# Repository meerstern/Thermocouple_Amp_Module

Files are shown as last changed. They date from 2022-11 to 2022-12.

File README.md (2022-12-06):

# 熱電対センサアンプ基板
Thermocouple_Amp_Module with MAX31855K & STM32G030F6P6

## 概要
  * [MAX31855K][1]を使用したK型熱電対センサ用のアンプ基板です  
  * K型熱電対の温度に応じてアナログ出力(0~3.3V)を得ることが可能です  
  * JP1のOpenでローゲインモード(既定)、Closeでハイゲインモードの切替が可能です  
  * ローゲインモードの場合、ゲイン200℃/V、オフセット1.25Vで、温度範囲は-240℃～400℃です  
  * ハイゲインモードの場合、ゲイン400℃/V、オフセット1.25Vで、温度範囲は-270℃～800℃です  

  * 計算式  $K型熱電対温度 ℃ ＝ ゲイン × (電圧出力-オフセット)$  

 * 電源投入直後及び熱電対の断線や短絡等の異常時は基板上のエラーLED(赤色)が点灯します  
 * STM32G030F6P6マイコンのコードを公開しているため、ゲインやオフセットを変更することが可能です  
 * アナログ出力はマイコンのPWM出力(16bit)からローパスフィルタとバッファを介して出力しています  
 * 電源電圧が5Vであってもアナログ出力範囲は0~3.3Vです  
 * 変換精度±4℃、最大±6℃  
 * アナログ出力範囲の上限及び下限ではオフセット電圧や飽和電圧の影響で温度精度が低下する場合があります  
 * 電源電圧が3.3Vより低い場合、アナログ出力が低下する場合があります  
 * ファーム書き換えはSTLink及びSTM32CubeProgrammerが別途必要です  
 * 電源電圧：3.3V~5V  
 * 基板サイズ25mm x35mm、M3x2 幅19mm  
 
 ## 販売サイト
  * [スイッチサイエンス][2]
 
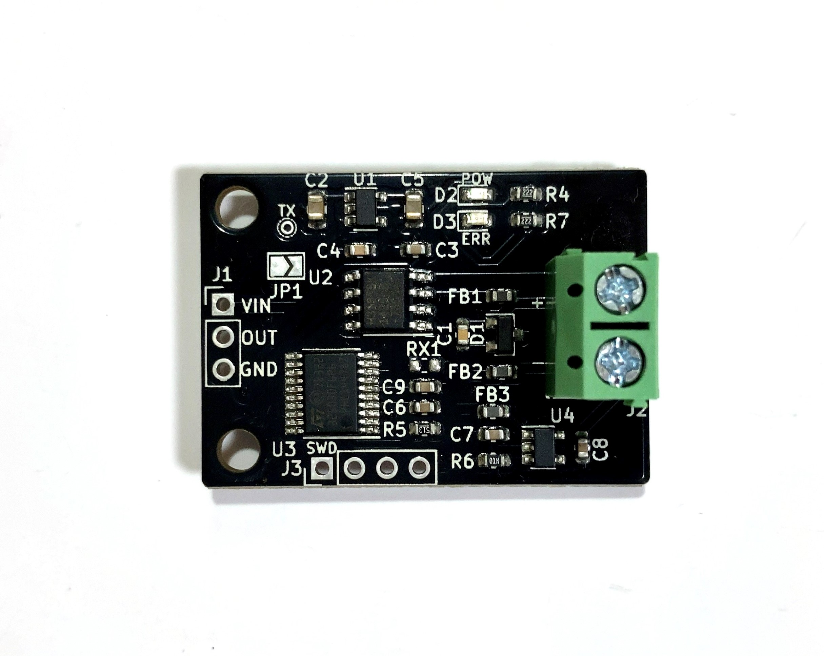
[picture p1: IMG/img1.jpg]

   
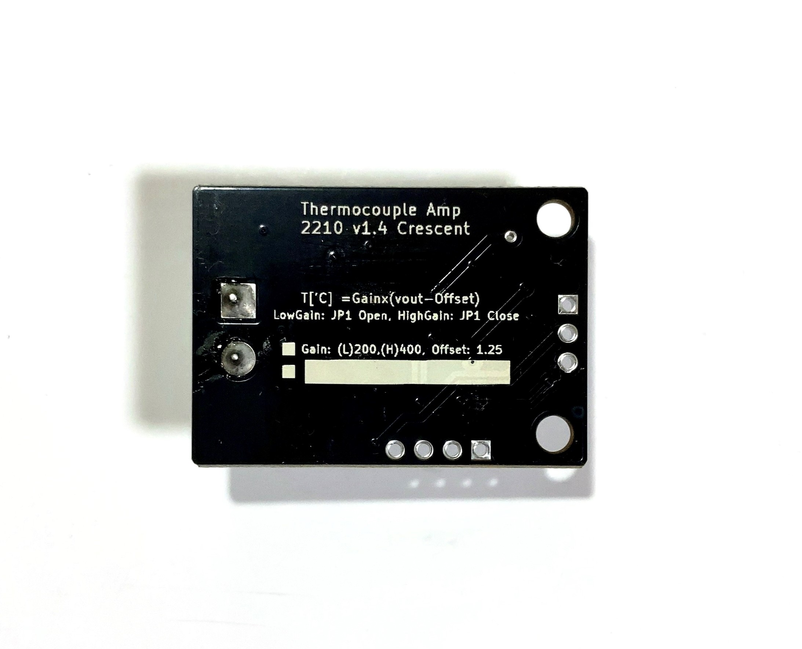
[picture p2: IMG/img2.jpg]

 
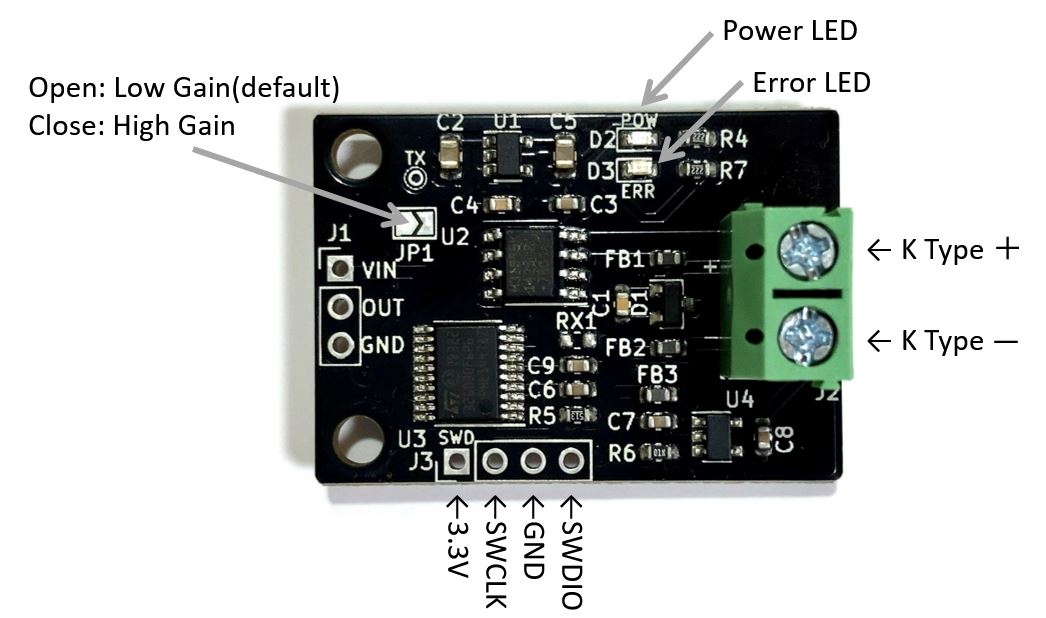
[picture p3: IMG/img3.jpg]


[1]: https://www.maximintegrated.com/jp/products/interface/sensor-interface/MAX31855.html
[2]: https://www.switch-science.com/products/8651

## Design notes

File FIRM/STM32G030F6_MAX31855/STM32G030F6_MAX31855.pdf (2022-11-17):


22/09/2022

STM32G030F6_MAX31855 Project Configuration Report

## 1. Description

### 1.1. Project

Project Name | STM32G030F6_MAX31855
Board Name | custom
Generated with: | STM32CubeMX 6.2.1
Date | 09/22/2022

### 1.2. MCU

MCU Series | STM32G0
MCU Line | STM32G0x0 Value line
MCU name | STM32G030F6Px
MCU Package | TSSOP20
MCU Pin number | 29

### 1.3. Core(s) information

Core(s) | ARM Cortex-M0+

## 2. Pinout Configuration

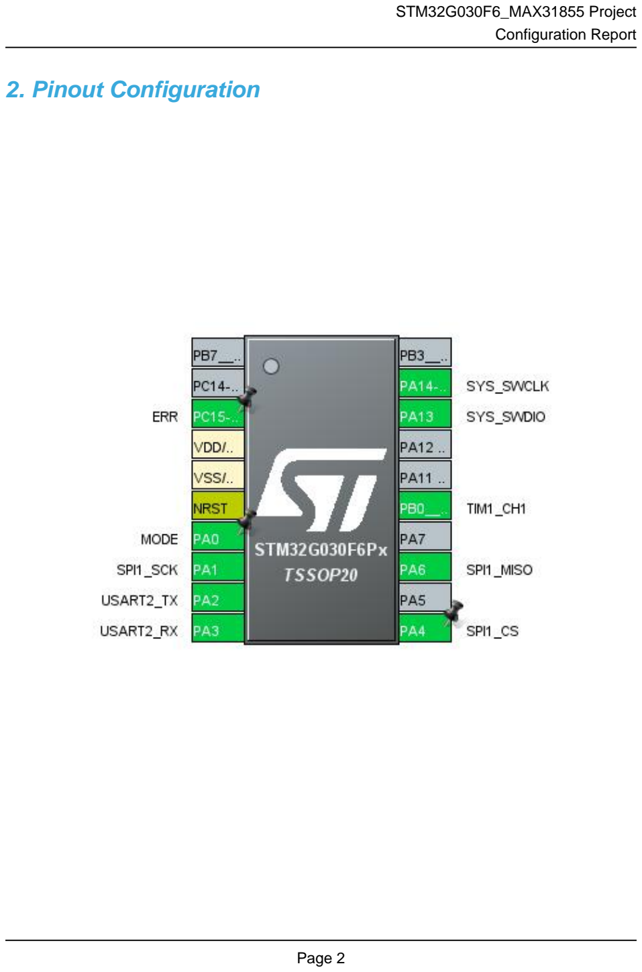
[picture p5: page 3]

## 3. Pins Configuration

Pin Number TSSOP20 | Pin Name (function after reset) | Pin Type | Alternate Function(s) | Label
3 | PC15-OSC32_OUT (PC15) * | I/O | GPIO_Output | ERR
4 | VDD/VDDA | Power
5 | VSS/VSSA | Power
6 | NRST | Reset
7 | PA0 * | I/O | GPIO_Input | MODE
8 | PA1 | I/O | SPI1_SCK
9 | PA2 | I/O | USART2_TX
10 | PA3 | I/O | USART2_RX
11 | PA4 * | I/O | GPIO_Output | SPI1_CS
13 | PA6 | I/O | SPI1_MISO
15 | PA8 | I/O | TIM1_CH1
18 | PA13 | I/O | SYS_SWDIO
19 | PA14-BOOT0 | I/O | SYS_SWCLK

* The pin is affected with an I/O function

## 4. Clock Tree Configuration

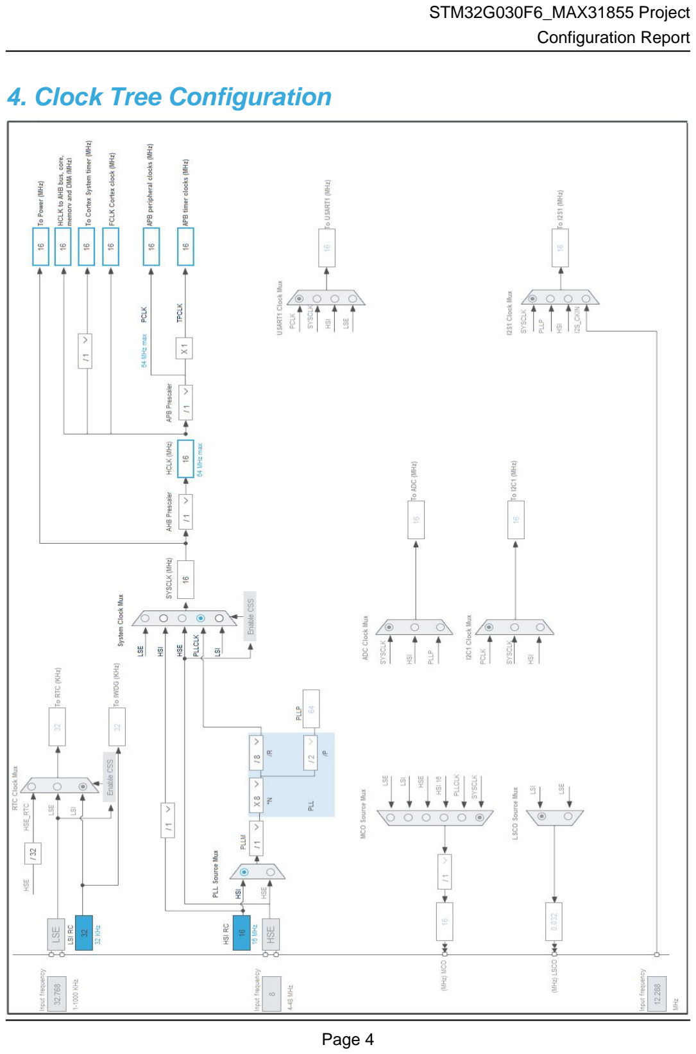
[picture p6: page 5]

## 5. Software Project

### 5.1. Project Settings

Name | Value
Project Name | STM32G030F6_MAX31855
Project Folder | D:\30_ARM_WS\workspace\STM32G030F6_MAX31855
Toolchain / IDE | SW4STM32
Firmware Package Name and Version | STM32Cube FW_G0 V1.4.1
Application Structure | Advanced
Generate Under Root | Yes
Do not generate the main() | No
Minimum Heap Size | 0x200
Minimum Stack Size | 0x400

### 5.2. Code Generation Settings

Name | Value
STM32Cube MCU packages and embedded software | Copy only the necessary library files
Generate peripheral initialization as a pair of '.c/.h' files | No
Backup previously generated files when re-generating | No
Keep User Code when re-generating | Yes
Delete previously generated files when not re-generated | Yes
Set all free pins as analog (to optimize the power consumption) | No
Enable Full Assert | No

### 5.3. Advanced Settings - Generated Function Calls

Rank | Function Name | Peripheral Instance Name
1 | MX_GPIO_Init | GPIO
2 | SystemClock_Config | RCC
3 | MX_SPI1_Init | SPI1
4 | MX_TIM1_Init | TIM1
5 | MX_USART2_UART_Init | USART2

## 6. Power Consumption Calculator report

### 6.1. Microcontroller Selection

Series | STM32G0
Line | STM32G0x0 Value line
MCU | STM32G030F6Px
Datasheet | DS12991_Rev1

### 6.2. Parameter Selection

Temperature | 25
Vdd | 3.0

### 6.3. Battery Selection

Battery | Li-SOCL2(AAA700)
Capacity | 700.0 mAh
Self Discharge | 0.08 %/month
Nominal Voltage | 3.6 V
Max Cont Current | 10.0 mA
Max Pulse Current | 30.0 mA
Cells in series | 1
Cells in parallel | 1

### 6.4. Sequence

Step | Step1 | Step2
Mode | RUN | STOP1
Vdd | 3.0 | 3.0
Voltage Source | Battery | Battery
Range | Range1-High | NoRange
Fetch Type | FLASH | Flash-PowerDown
CPU Frequency | 64 MHz | 16 MHz
Clock Configuration | HSI PLL | HSI
Clock Source Frequency | 16 MHz | 16 MHz
Peripherals
Additional Cons. | 0 mA | 0 mA
Average Current | 5.77 mA | 3.7 µA
Duration | 0.1 ms | 0.9 ms
DMIPS | 80.0 | 0.0
Ta Max | 128.68 | 130
Category | In DS Table | In DS Table

### 6.5. Results

Sequence Time | 1 ms | Average Current | 580.33 µA
Battery Life | 1 month, 19 days, 18 hours | Average DMIPS | 80.0 DMIPS

### 6.6. Chart

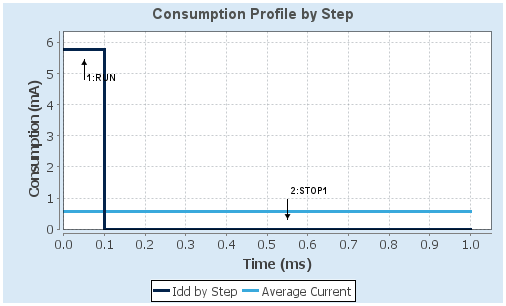
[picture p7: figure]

## 7. Peripherals and Middlewares Configuration

### 7.1. RCC

7.1.1. Parameter Settings:

System Parameters:

VDD voltage (V) | 3.3
Instruction Cache | Enabled
Prefetch Buffer | Disabled
Data Cache | Enabled
Flash Latency(WS) | 0 WS (1 CPU cycle)
RCC Parameters:
HSI Calibration Value | 64
HSE Startup Timout Value (ms) | 100
LSE Startup Timout Value (ms) | 5000
Power Parameters:
Power Regulator Voltage Scale | Power Regulator Voltage Scale 1
Peripherals Clock Configuration:
Generate the peripherals clock configuration | TRUE

### 7.2. SPI1

Mode: Receive Only Master
7.2.1. Parameter Settings:

Basic Parameters:

Frame Format | Motorola
Data Size | 8 Bits
First Bit | MSB First
Clock Parameters:
Prescaler (for Baud Rate) | 16 *
Baud Rate | 1000.0 KBits/s *
Clock Polarity (CPOL) | Low
Clock Phase (CPHA) | 1 Edge
Advanced Parameters:
CRC Calculation | Disabled
NSSP Mode | Enabled
NSS Signal Type | Software

### 7.3. SYS

mode: Debug
Timebase Source: SysTick

### 7.4. TIM1

Channel1: Output Compare CH1
7.4.1. Parameter Settings:

Counter Settings:

Prescaler (PSC - 16 bits value) | 0
Counter Mode | Up
Counter Period (AutoReload Register - 16 bits value ) | 65535
Internal Clock Division (CKD) | No Division
Repetition Counter (RCR - 16 bits value) | 0
auto-reload preload | Disable
Trigger Output (TRGO) Parameters:
Master/Slave Mode (MSM bit) | Disable (Trigger input effect not delayed)
Trigger Event Selection TRGO | Reset (UG bit from TIMx_EGR)
Trigger Event Selection TRGO2 | Reset (UG bit from TIMx_EGR)
Break And Dead Time management - BRK Configuration:
BRK State | Disable
BRK Polarity | High
BRK Filter (4 bits value) | 0
BRK Sources Configuration
- Digital Input | Disable
Break And Dead Time management - BRK2 Configuration:
BRK2 State | Disable
BRK2 Polarity | High
BRK2 Filter (4 bits value) | 0
BRK2 Sources Configuration
- Digital Input | Disable
Break And Dead Time management - Output Configuration:
Automatic Output State | Disable
Off State Selection for Run Mode (OSSR) | Disable
Off State Selection for Idle Mode (OSSI) | Disable
Lock Configuration | Off
Clear Input:
Clear Input Source | Disable

Output Compare Channel 1:

Mode | Frozen (used for Timing base)
Pulse (16 bits value) | 0
Output compare preload | Disable
CH Polarity | High
CH Idle State | Reset

### 7.5. USART2

Mode: Asynchronous
7.5.1. Parameter Settings:

Basic Parameters:

Baud Rate | 9600 *
Word Length | 8 Bits (including Parity)
Parity | None
Stop Bits | 1
Advanced Parameters:
Data Direction | Receive and Transmit
Over Sampling | 16 Samples
Single Sample | Disable
ClockPrescaler | 1
Advanced Features:
TX Pin Active Level Inversion | Disable
RX Pin Active Level Inversion | Disable
Data Inversion | Disable
TX and RX Pins Swapping | Disable
Overrun | Enable
DMA on RX Error | Enable
MSB First | Disable

* User modified value

## 8. System Configuration

### 8.1. GPIO configuration

IP | Pin | Signal | GPIO mode | GPIO pull/up pull down | Max Speed | User Label
SPI1 | PA1 | SPI1_SCK | Alternate Function Push Pull | No pull-up and no pull-down | Low
| PA6 | SPI1_MISO | Alternate Function Push Pull | No pull-up and no pull-down | Low
SYS | PA13 | SYS_SWDIO | n/a | n/a | n/a
| PA14-BOOT0 | SYS_SWCLK | n/a | n/a | n/a
TIM1 | PA8 | TIM1_CH1 | Alternate Function Push Pull | No pull-up and no pull-down | Low
USART2 | PA2 | USART2_TX | Alternate Function Push Pull | No pull-up and no pull-down | Low
| PA3 | USART2_RX | Alternate Function Push Pull | No pull-up and no pull-down | Low
GPIO | PC15-OSC32_OU T (PC15) | GPIO_Output | Output Push Pull | No pull-up and no pull-down | Low | ERR
| PA0 | GPIO_Input | Input mode | Pull-up * | n/a | MODE
| PA4 | GPIO_Output | Output Push Pull | No pull-up and no pull-down | Low | SPI1_CS

### 8.2. DMA configuration

nothing configured in DMA service

### 8.3. NVIC configuration

8.3.1. NVIC
Interrupt Table | Enable | Preenmption Priority | SubPriority
Non maskable interrupt | true | 0 | 0
Hard fault interrupt | true | 0 | 0
System service call via SWI instruction | true | 0 | 0
Pendable request for system service | true | 0 | 0
System tick timer | true | 0 | 0
Flash global interrupt | unused
RCC global interrupt | unused
TIM1 break, update, trigger and commutation interrupts | unused
TIM1 capture compare interrupt | unused
SPI1 global interrupt | unused
USART2 global interrupt / USART2 wake-up interrupt through EXTI line 26 | unused
8.3.2. NVIC Code generation
Enabled interrupt Table | Select for init sequence ordering | Generate IRQ handler | Call HAL handler
Non maskable interrupt | false | true | false
Hard fault interrupt | false | true | false
System service call via SWI instruction | false | true | false
Pendable request for system service | false | true | false
System tick timer | false | true | true

* User modified value

## 9. System Views

9.1. Category view
9.1.1. Current

## 10. Docs & Resources

Type | Link
Datasheet | http://www.st.com/resource/en/datasheet/DM00613878.pdf
Reference manual | http://www.st.com/resource/en/reference_manual/DM00463896.pdf
Programming manual | http://www.st.com/resource/en/programming_manual/DM00104451.pdf
Errata sheet | http://www.st.com/resource/en/errata_sheet/DM00625292.pdf
Application note | http://www.st.com/resource/en/application_note/CD00160362.pdf
Application note | http://www.st.com/resource/en/application_note/CD00167594.pdf
Application note | http://www.st.com/resource/en/application_note/CD00259245.pdf
Application note | http://www.st.com/resource/en/application_note/CD00264342.pdf
Application note | http://www.st.com/resource/en/application_note/CD00264379.pdf
Application note | http://www.st.com/resource/en/application_note/DM00042534.pdf
Application note | http://www.st.com/resource/en/application_note/DM00072315.pdf
Application note | http://www.st.com/resource/en/application_note/DM00081379.pdf
Application note | http://www.st.com/resource/en/application_note/DM00129215.pdf
Application note | http://www.st.com/resource/en/application_note/DM00151811.pdf
Application note | http://www.st.com/resource/en/application_note/DM00257177.pdf
Application note | http://www.st.com/resource/en/application_note/DM00272912.pdf
Application note | http://www.st.com/resource/en/application_note/DM00226326.pdf
Application note | http://www.st.com/resource/en/application_note/DM00355687.pdf
Application note | http://www.st.com/resource/en/application_note/DM00311483.pdf
Application note | http://www.st.com/resource/en/application_note/DM00380469.pdf
Application note | http://www.st.com/resource/en/application_note/DM00395696.pdf
Application note | http://www.st.com/resource/en/application_note/DM00493651.pdf
Application note | http://www.st.com/resource/en/application_note/DM00535045.pdf
Application note | http://www.st.com/resource/en/application_note/DM00443870.pdf
Application note | http://www.st.com/resource/en/application_note/DM00449912.pdf

Application note | http://www.st.com/resource/en/application_note/DM00483659.pdf
Application note | http://www.st.com/resource/en/application_note/DM00536349.pdf
Application note | http://www.st.com/resource/en/application_note/DM00625700.pdf
Application note | http://www.st.com/resource/en/application_note/DM00725181.pdf

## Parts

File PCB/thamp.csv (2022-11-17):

ID | 参照記号 | パッケージ | 数 | 名称 | Supplier and ref
1 | REF1,REF2 | MountingHole_3.2mm_M3 | 2 | MountingHole_3.2mm_M3
2 | FB3,FB2,FB1 | L_0603_1608Metric | 3 | 470ohm
3 | JP1 | SolderJumper-2_P1.3mm_Open_TrianglePad1.0x1.5mm | 1 | SW_DIP_x01
4 | U3 | TSSOP-20_4.4x6.5mm_P0.65mm | 1 | STM32G030F
5 | RX1 | R_0603_1608Metric | 1 | 0
6 | C9,C8,C7,C6,C3 | C_0603_1608Metric | 5 | 0.1u
7 | U4 | SOT-23-5 | 1 | LM321
8 | U2 | SOIC-8_3.9x4.9mm_P1.27mm | 1 | MAX31855KASA
9 | U1 | SOT-23-5 | 1 | LD3985M33R_SOT23
10 | R7,R4 | R_0603_1608Metric | 2 | 2.1k
11 | R6 | R_0603_1608Metric | 1 | 10
12 | R5 | R_0603_1608Metric | 1 | 51k
13 | J3 | PinHeader_1x04_P2.54mm_Vertical | 1 | SWD
14 | J2 | TerminalBlock_bornier-2_P5.08mm | 1 | Thermocouple
15 | J1 | PinHeader_1x03_P2.54mm_Vertical | 1 | Conn_01x03
16 | D3 | LED_0603_1608Metric | 1 | ERR
17 | D2 | LED_0603_1608Metric | 1 | POW
18 | D1 | SOT-23 | 1 | NUP2105L
19 | C5,C2 | C_0805_2012Metric | 2 | 10u
20 | C4,C1 | C_0603_1608Metric | 2 | 0.01u

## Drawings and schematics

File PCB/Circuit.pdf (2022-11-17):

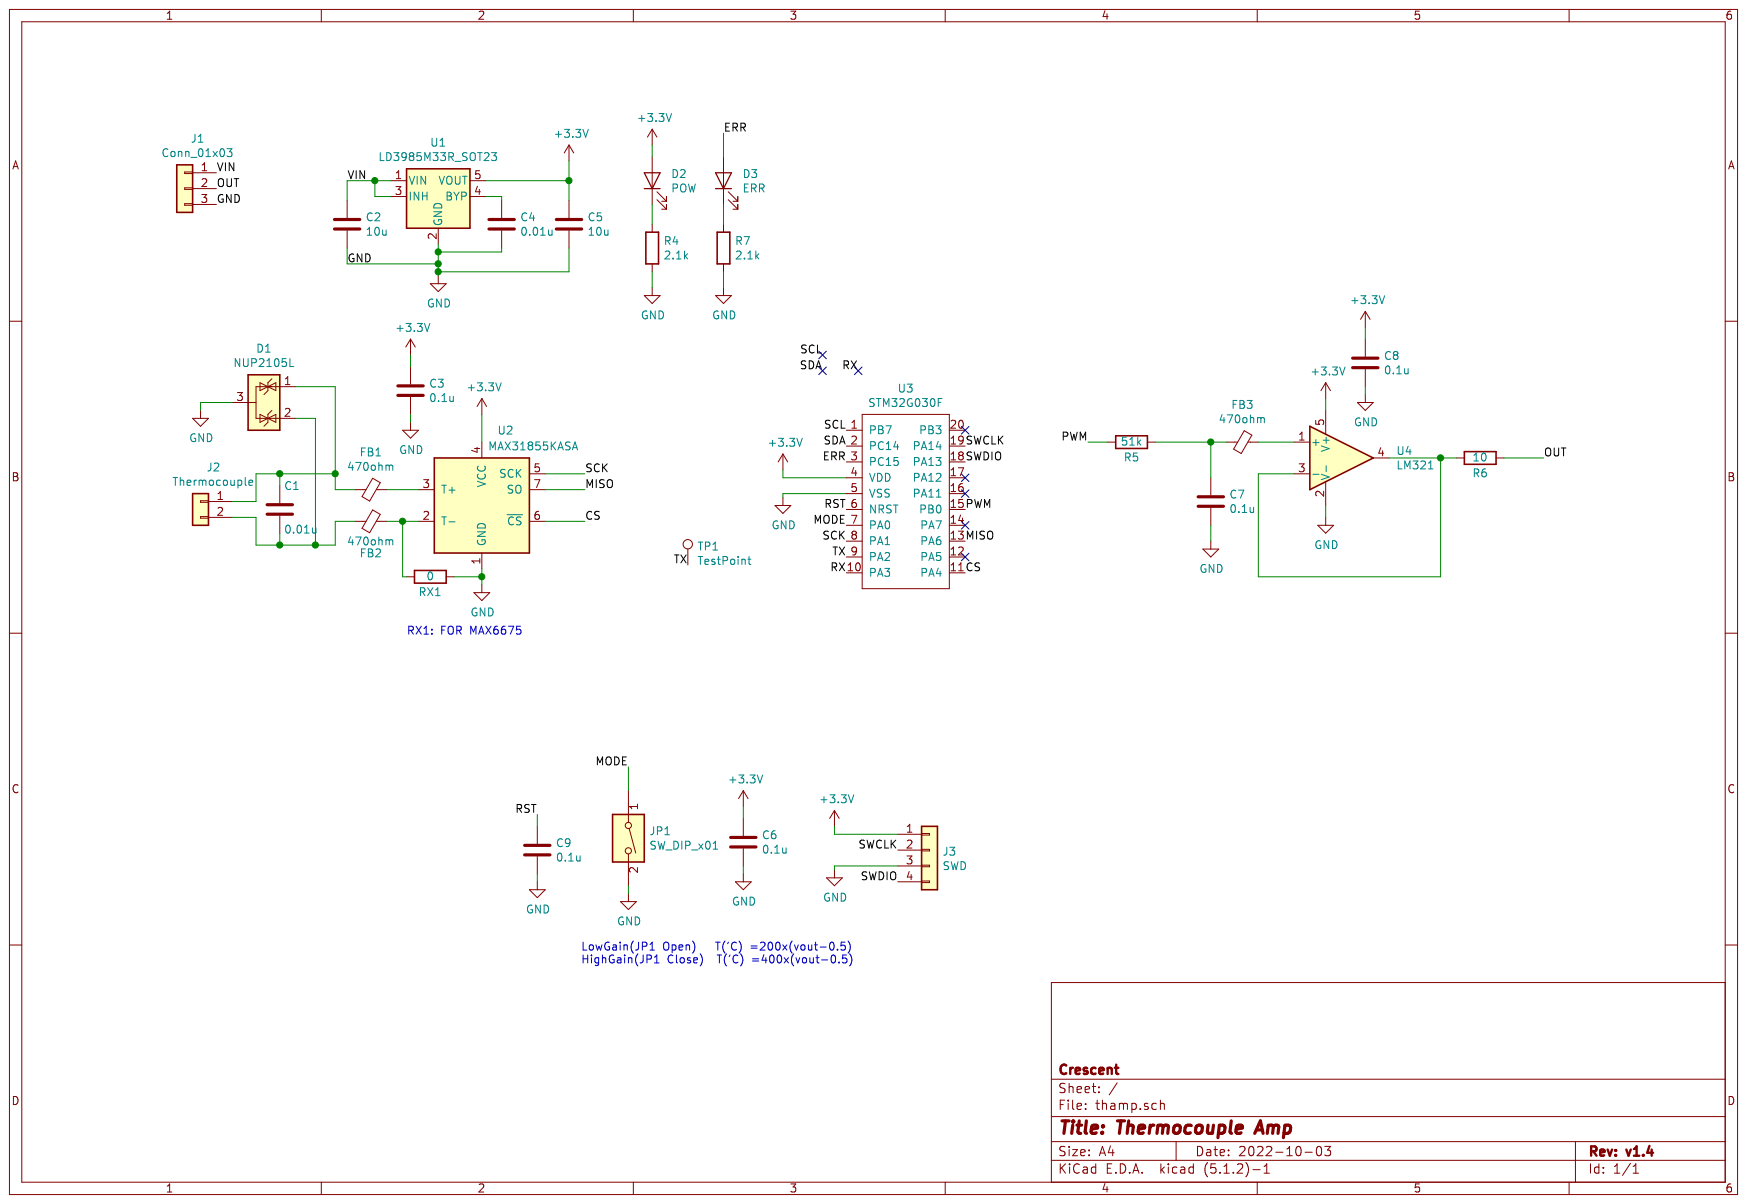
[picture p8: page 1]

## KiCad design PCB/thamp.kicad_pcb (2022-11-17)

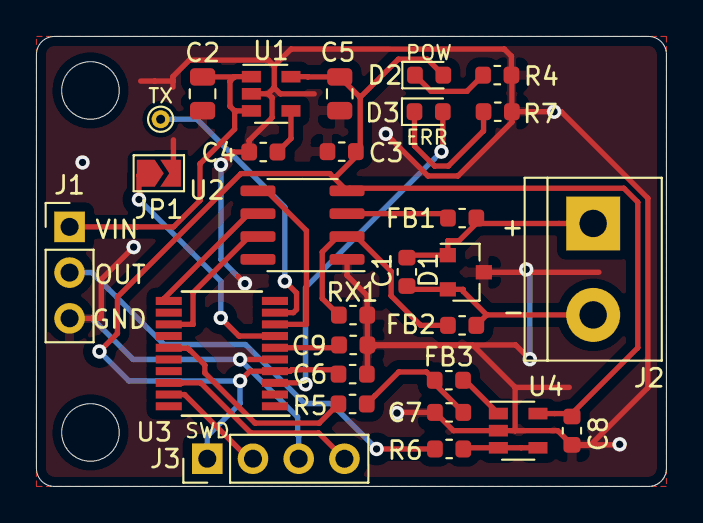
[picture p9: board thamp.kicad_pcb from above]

Board: 2 copper layers, 35.0 x 25.0 mm, 31 parts (0 on the bottom side), 24 nets.

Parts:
C1, C4: 0.01u; C_0603_1608Metric
C2, C5: 10u; C_0805_2012Metric
C3, C6, C7, C8, C9: 0.1u; C_0603_1608Metric
D1: NUP2105L; SOT-23
D2: POW; LED_0603_1608Metric
D3: ERR; LED_0603_1608Metric
FB1, FB2, FB3: 470ohm; L_0603_1608Metric
J1: Conn_01x03; PinHeader_1x03_P2.54mm_Vertical
J2: Thermocouple; TerminalBlock_bornier-2_P5.08mm
J3: SWD; PinHeader_1x04_P2.54mm_Vertical
JP1: SW_DIP_x01; SolderJumper-2_P1.3mm_Open_TrianglePad1.0x1.5mm
R4, R7: 2.1k; R_0603_1608Metric
R5: 51k; R_0603_1608Metric
R6: 10; R_0603_1608Metric
REF1, REF2: MountingHole_3.2mm_M3
RX1: 0; R_0603_1608Metric
TP1: TestPoint; TestPoint_THTPad_D1.0mm_Drill0.5mm
U1: LD3985M33R_SOT23; SOT-23-5
U2: MAX31855KASA; SOIC-8_3.9x4.9mm_P1.27mm
U3: STM32G030F; TSSOP-20_4.4x6.5mm_P0.65mm
U4: LM321; SOT-23-5

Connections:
+3V3: C3.1, C5.1, C6.1, C8.1, D2.2, J3.1, U1.5, U2.4, U3.4, U4.5
/CS: U2.6, U3.11
/ERR: D3.2, U3.3
/MISO: U2.7, U3.13
/MODE: JP1.1, U3.7
/OUT: J1.2, R6.2
/PWM: R5.1, U3.15
/RST: C9.1, U3.6
/SCK: U2.5, U3.8
/SWCLK: J3.2, U3.19
/SWDIO: J3.4, U3.18
/TX: TP1.1, U3.9
/VIN: C2.1, J1.1, U1.1, U1.3
GND: C2.2, C3.2, C4.2, C5.2, C6.2, C7.2, C8.2, C9.2, D1.3, J1.3, J3.3, JP1.2, R4.2, R7.2, RX1.2, U1.2, U2.1, U3.5, U4.2
unnamed: C1.1, D1.1, FB1.2, J2.1
unnamed: C1.2, D1.2, FB2.2, J2.2
unnamed: C4.1, U1.4
unnamed: C7.1, FB3.2, R5.2
unnamed: D2.1, R4.1
unnamed: D3.1, R7.1
unnamed: FB1.1, U2.3
unnamed: FB2.1, RX1.1, U2.2
unnamed: FB3.1, U4.1
unnamed: R6.1, U4.3, U4.4

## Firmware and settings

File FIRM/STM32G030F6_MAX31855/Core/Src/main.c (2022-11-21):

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
/* Includes ------------------------------------------------------------------*/
#include "main.h"

/* USER CODE BEGIN Includes */
#include <stdio.h>
#include <stdbool.h>
/* USER CODE END Includes */

/* USER CODE BEGIN PM */


#define SETTING1
//#define SETTING2
//#define SETTING3

#define AMP_OFFSET		0.000f



#ifdef SETTING1
	#define LGAIN 		200.0f	 // 'C/V
	#define HGAIN		400.0f	 // 'C/V
	#define VOFFSET 	1.25f	 // V/'C
	#define MAXDUTY		4095.0f
	#define MINVOLT		0.001f
	#define MAXVOLT		3.280f
#endif

#ifdef SETTING2
	#define LGAIN 		200.0f	 // 'C/V
	#define HGAIN		400.0f	 // 'C/V
	#define VOFFSET 	0.5f	 // V/'C
	#define MAXDUTY		4095.0f
	#define MINVOLT		0.001f
	#define MAXVOLT		3.280f
#endif

#ifdef SETTING3
	#define LGAIN 		100.0f	 // 'C/V
	#define HGAIN		256.41f	 // 'C/V
	#define VOFFSET 	0.0f	 // V/'C
	#define MAXDUTY		4095.0f
	#define MINVOLT		0.001f
	#define MAXVOLT		3.280f
#endif

#define USE_DEBUG

/* USER CODE END PM */

SPI_HandleTypeDef hspi1;

TIM_HandleTypeDef htim1;

UART_HandleTypeDef huart2;

/* USER CODE BEGIN PV */
volatile bool HighGainMode=false;
#ifdef USE_DEBUG
int _write( int file, char *ptr, int len )
{
  HAL_UART_Transmit(&huart2,(uint8_t*) ptr, len, 1000);
  return len;
}
#endif
/* USER CODE END PV */

void SystemClock_Config(void);
static void MX_GPIO_Init(void);
static void MX_SPI1_Init(void);
static void MX_TIM1_Init(void);
static void MX_USART2_UART_Init(void);
/* USER CODE BEGIN 0 */
void GetTmp(float *tmp, uint8_t *err)
{
	uint8_t 	rdata[4]={0x00};
	uint8_t 	wdata[4]={0x00};

	uint32_t    rawData;
	int32_t 	valData;
	float 		valFloat;


	//CS Low
	LL_GPIO_ResetOutputPin(SPI1_CS_GPIO_Port, SPI1_CS_Pin);
	//Recieve
	HAL_SPI_TransmitReceive(&hspi1, wdata, rdata, 4, 0xFFF);
	//CS High
	LL_GPIO_SetOutputPin(SPI1_CS_GPIO_Port, SPI1_CS_Pin);

	rawData = rdata[0];
	rawData <<= 8;
	rawData |= rdata[1];
	rawData <<= 8;
	rawData |= rdata[2];
	rawData <<= 8;
	rawData |= rdata[3];
	valData=rawData;

	float 		internal;
	internal = (valData >> 4) & 0x7FF;
	internal *= 0.0625;
	if ((valData >> 4) & 0x800)
		internal *= -1;

	if (valData & 0x80000000)
		valData = 0xFFFFC000 | ((valData >> 18) & 0x00003FFF);
	else
		valData >>= 18;
	valFloat=valData;
	valFloat *= 0.25;

	//printf("DATA:%2X %2X %2X %2X \t",rdata[0],rdata[1],rdata[2],rdata[3]);

	*tmp=valFloat;
	*err=rdata[3]&0x03;

}

void ConvertTemp2Duty(float temp, uint8_t err, uint16_t *duty)
{
	float volt=0.0f;
	if(HighGainMode==true)
		volt= temp/HGAIN + VOFFSET+(AMP_OFFSET);
	else
		volt= temp/LGAIN + VOFFSET+(AMP_OFFSET);

	float dutyValue=0;
	if(volt<0)
		volt=0.0f;

	dutyValue = volt/(MAXVOLT-MINVOLT)*MAXDUTY;

	if(dutyValue>4095.0f)
		dutyValue=MAXDUTY;
	*duty=(uint16_t)dutyValue;

#ifdef USE_DEBUG
	//printf("duty:%d, v:%f, err:%d,",*duty, volt-(AMP_OFFSET), err);
#endif

}
/* USER CODE END 0 */

/**
  * @brief  The application entry point.
  * @retval int
  */
int main(void)
{
  /* MCU Configuration--------------------------------------------------------*/

  /* Reset of all peripherals, Initializes the Flash interface and the Systick. */
  HAL_Init();

  /* Configure the system clock */
  SystemClock_Config();

  /* Initialize all configured peripherals */
  MX_GPIO_Init();
  MX_SPI1_Init();
  MX_TIM1_Init();
  MX_USART2_UART_Init();
  /* USER CODE BEGIN 2 */

  if((LL_GPIO_ReadInputPort(MODE_GPIO_Port) & MODE_Pin)==0)
  {
	  HighGainMode=true;
  }

  uint16_t duty=0;
  float tmp=0.0f;
  uint8_t err=0;
  HAL_TIM_OC_Start_IT(&htim1, TIM_CHANNEL_1);
  __HAL_TIM_SET_COMPARE( &htim1, TIM_CHANNEL_1, duty);
#ifdef USE_DEBUG
  //printf("Init OK!!\r\n");
#endif

  /* USER CODE END 2 */

  /* Infinite loop */
  /* USER CODE BEGIN WHILE */
  while (1)
  {
    /* USER CODE END WHILE */

    /* USER CODE BEGIN 3 */
	  GetTmp(&tmp, &err);
	  ConvertTemp2Duty(tmp, err, &duty);
	  __HAL_TIM_SET_COMPARE( &htim1, TIM_CHANNEL_1, duty);

	  if(err!=0)
		  HAL_GPIO_WritePin(ERR_GPIO_Port, ERR_Pin, GPIO_PIN_SET);
	  else
		  HAL_GPIO_WritePin(ERR_GPIO_Port, ERR_Pin, GPIO_PIN_RESET);
#ifdef USE_DEBUG
	  printf("%2.2f\r\n",tmp);
#endif
	  HAL_Delay(80);
  }
  /* USER CODE END 3 */
}

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


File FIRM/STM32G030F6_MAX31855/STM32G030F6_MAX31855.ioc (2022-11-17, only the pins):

Mcu.UserName=STM32G030F6Px
PA0.GPIO_Label=MODE
PA0.Signal=GPIO_Input
PA1.Signal=SPI1_SCK
PA13.Signal=SYS_SWDIO
PA14-BOOT0.Signal=SYS_SWCLK
PA2.Signal=USART2_TX
PA3.Signal=USART2_RX
PA4.GPIO_Label=SPI1_CS
PA4.Signal=GPIO_Output
PA6.Signal=SPI1_MISO
PA7.Signal=SPI1_MOSI
PA8.Signal=S_TIM1_CH1

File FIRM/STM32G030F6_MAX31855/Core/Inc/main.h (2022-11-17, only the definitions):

#define ERR_Pin LL_GPIO_PIN_15
#define ERR_GPIO_Port GPIOC
#define MODE_Pin LL_GPIO_PIN_0
#define MODE_GPIO_Port GPIOA
#define SPI1_CS_Pin LL_GPIO_PIN_4
#define SPI1_CS_GPIO_Port GPIOA

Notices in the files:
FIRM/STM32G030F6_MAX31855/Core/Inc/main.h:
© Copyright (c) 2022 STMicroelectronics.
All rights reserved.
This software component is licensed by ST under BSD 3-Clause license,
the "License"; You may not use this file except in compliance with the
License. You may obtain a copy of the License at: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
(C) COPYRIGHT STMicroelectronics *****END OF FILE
